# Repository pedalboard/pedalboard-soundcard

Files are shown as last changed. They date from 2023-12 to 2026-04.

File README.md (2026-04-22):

# Pedalboard Soundcard

I²S audio codec HAT for Raspberry Pi — ADC + DAC for the [Open Pedalboard](https://github.com/pedalboard) system.

**[Documentation →](https://pedalboard.github.io/pedalboard-soundcard/latest/)**

Top View

## Features

- TI Burr-Brown PCM1863 ADC (106dB SNR) + PCM5242 DAC (112dB SNR)
- Stereo differential input (guitar) + stereo output (amp)
- I²S interface to Raspberry Pi GPIO header
- Low-latency audio path for real-time effects
- Raspberry Pi HAT form factor

## Links

- [Interactive schematic & PCB viewer](https://pedalboard.github.io/pedalboard-soundcard/latest/board/)
- [Digi-Key shared list](https://www.digikey.ch/de/mylists/list/OT2O5ZLS9K)

## Development Setup

### Prerequisites

- [KiCad](https://www.kicad.org/) 10+
- [KiKit](https://github.com/yaqwsx/KiKit) (panelization)
- [mise](https://mise.jdx.dev/) (environment management)

### Environment

The schematic references KiKit's symbol and footprint libraries via the `${KIKIT_LIB}` environment variable. This is set per-machine using a `mise.local.toml` file (gitignored).

After cloning, create `mise.local.toml` in the project root:

```toml
[env]
KIKIT_LIB = "/path/to/kikit/resources"
```

Find your KiKit resources path with:

```sh
python3 -c "import kikit, os; print(os.path.join(os.path.dirname(kikit.__file__), 'resources'))"
```

Then trust the config:

```sh
mise trust mise.local.toml
```

### Checks

Run ERC and DRC:

```sh
make test
```

## Acknowledgements

Based on Dave Vandenbout's [RPi Hat Template](https://github.com/devbisme/RPi_Hat_Template).
Schematics derived from Jośe Fernando Moyano's [ZynADC](https://github.com/zynthian/zynthian-hw/tree/master/ZynADAC) ([CC BY-SA 4.0](https://creativecommons.org/licenses/by-sa/4.0/)).

## License



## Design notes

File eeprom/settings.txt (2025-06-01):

########################################################################
# EEPROM settings text file
#
# Edit this file for your particular board and run through eepmake tool,
# then use eepflash tool to write to attached HAT ID EEPROM 
#
# Tools available:
#  eepmake   Parses EEPROM text file and creates binary .eep file
#  eepdump   Dumps a binary .eep file as human readable text (for debug)
#  eepflash  Write or read .eep binary image to/from HAT EEPROM
#
########################################################################

########################################################################
# Vendor info

# 128 bit UUID. If left at zero eepmake tool will auto-generate
# RFC 4122 compliant UUID
product_uuid 8b12a93d-56c9-435f-b7e0-9d4ae88997cc

# 16 bit product id
product_id 0x0001

# 16 bit product version
product_ver 0x0001

# ASCII vendor string  (max 255 characters)
vendor "github.com/pedalboard"

# ASCII product string (max 255 characters)
product "pedalboard-soundcard"

########################################################################
# GPIO bank settings, set to nonzero to change from the default.
# NOTE these setting can only be set per BANK, uncommenting any of
# these will force the bank to use the custom setting.

# drive strength, 0=default, 1-8=2,4,6,8,10,12,14,16mA, 9-15=reserved
gpio_drive 0

# 0=default, 1=slew rate limiting, 2=no slew limiting, 3=reserved
gpio_slew 0

# 0=default, 1=hysteresis disabled, 2=hysteresis enabled, 3=reserved
gpio_hysteresis 0

# If board back-powers Pi via 5V GPIO header pins:
# 0 = board does not back-power
# 1 = board back-powers and can supply the Pi with a minimum of 1.3A
# 2 = board back-powers and can supply the Pi with a minimum of 2A
# 3 = reserved
# If back_power=2 then USB high current mode will be automatically 
# enabled on the Pi
back_power 0

########################################################################
# GPIO pins, uncomment for GPIOs used on board
# Options for FUNCTION: INPUT, OUTPUT, ALT0-ALT5
# Options for PULL: DEFAULT, UP, DOWN, NONE
# NB GPIO0 and GPIO1 are reserved for ID EEPROM so cannot be set

#         GPIO  FUNCTION  PULL
#         ----  --------  ----
#setgpio  2     INPUT     DEFAULT
#setgpio  3     INPUT     DEFAULT
#setgpio  4     INPUT     DEFAULT
#setgpio  5     INPUT     DEFAULT
#setgpio  6     INPUT     DEFAULT
#setgpio  7     INPUT     DEFAULT
#setgpio  8     INPUT     DEFAULT
#setgpio  9     INPUT     DEFAULT
#setgpio  10    INPUT     DEFAULT
#setgpio  11    INPUT     DEFAULT
#setgpio  12    INPUT     DEFAULT
#setgpio  13    INPUT     DEFAULT
#setgpio  14    INPUT     DEFAULT
#setgpio  15    INPUT     DEFAULT
#setgpio  16    INPUT     DEFAULT
#setgpio  17    INPUT     DEFAULT
setgpio  18    INPUT     DEFAULT
setgpio  19    INPUT     DEFAULT
setgpio  20    INPUT     DEFAULT
setgpio  21    OUTPUT     DEFAULT
#setgpio  22    INPUT     DEFAULT
#setgpio  23    INPUT     DEFAULT
#setgpio  24    INPUT     DEFAULT
#setgpio  25    INPUT     DEFAULT
#setgpio  26    INPUT     DEFAULT
#setgpio  27    INPUT     DEFAULT

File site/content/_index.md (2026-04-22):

---
title: Overview
weight: 10
---

PCB 3D Render

I²S audio codec HAT for Raspberry Pi, designed for real-time guitar effects
processing in the [Open Pedalboard](https://github.com/pedalboard) system.

## Audio Specs

| | ADC (PCM1863) | DAC (PCM5242) |
|---|---|---|
| Resolution | 24-bit | 32-bit |
| Sample rate | up to 192 kHz | up to 384 kHz |
| SNR | 106 dB | 112 dB |
| THD+N | -93 dB | -93 dB |

## Features

- Stereo differential ADC input (guitar) + stereo DAC output (amp)
- TI Burr-Brown PCM1863 (ADC) and PCM5242 (DAC)
- I²S interface to Raspberry Pi GPIO header
- Low-latency audio path for real-time effects
- Raspberry Pi HAT form factor
- Dedicated low-noise LDO regulators for analog supply

## Related

- [Main Board](https://pedalboard.github.io/pedalboard-hw/latest/) — carrier board and MIDI controller
- [Display Board](https://pedalboard.github.io/pedalboard-display/latest/) — LED rings and OLED displays

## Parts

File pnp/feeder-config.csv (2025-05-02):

# |  | soundcard
# idx | type | id | name | part | enabled | location | refhole | lasthole
0 | strip | FDR18082b7f90ff6d45 | LH8-05 | Oscillator_SMD_Abracon_ASDMB-4Pin_2.5x2.0mm-24.576M | True | 2|0|0|0|-90.0000 | 2|75.1249|209.1139|8.4000|0 | 2|75.1620|213.3620|0|0
1 | strip | FDR18082da35e6da8a0 | LH8-06 | Oscillator_SMD_Abracon_ASDMB-4Pin_2.5x2.0mm-22.5792M | True | 2|0|0|0|-90.0000 | 2|63.9973|209.1139|8.4000|0 | 2|63.9791|213.4223|0|0
2 | strip | FDR18082ef066e21f88 | LH8-07 | SOT-23-5-AT24CS01-STUM | True | 2|0|0|0|90.0000 | 2|52.9366|209.1139|8.2000|0 | 2|53.0002|212.2299|0|0
3 | strip | FDR18082fce2e1989f6 | LH8-08 | SOT-23-5-NCP163 | True | 2|0|0|0|90.0000 | 2|41.6733|209.1139|8.1000|0 | 2|41.6980|213.2862|0|0
4 | strip | FDR17951439e7cd6f58 | LV8-01 | R_0805_2012Metric-100R | True | 2|0|0|0|90.0000 | 2|170.7350|198.7796|8.8000|0 | 2|170.8145|195.5087|0|0
5 | strip | FDR179514137f0b0a13 | LV8-02 | R_0805_2012Metric-470R | True | 2|0|0|0|90.0000 | 2|160.0952|198.7796|9.2000|0 | 2|160.0146|195.1096|0|0
6 | strip | FDR179513df1c674872 | LV8-03 | R_0805_2012Metric-10k | True | 2|0|0|0|90.0000 | 2|149.0850|198.7796|9.5000|0 | 2|149.0850|195.0340|0|0
7 | strip | FDR179513bd4cfa865e | LV8-04 | R_0805_2012Metric-100K | True | 2|0|0|0|90.0000 | 2|137.9097|198.7796|9.6000|0 | 2|137.8978|195.9155|0|0
8 | strip | FDR1795130d1cbdbcd5 | LV8-08 | LED_0805_2012Metric-LED_R | True | 2|0|0|0|-90.0000 | 2|92.9169|198.7796|9.5000|0 | 2|92.8505|191.6939|0|0
9 | strip | FDR18082c3ad540eca3 | LV8-09 | R_0805_2012Metric-3K9 | True | 2|0|0|0|90.0000 | 2|81.6007|198.7796|9.2000|0 | 2|81.6010|195.3340|0|0
10 | strip | FDR1795165a4c5adb67 | RH12-1 | HVQFN-32-1EP_5x5mm_P0.5mm_EP3.1x3.1mm_ThermalVias-PCM5242RHBR | True | 2|0|0|0|-90.0000 | 2|314.5132|210.8000|9.0000|0 | 2|314.5130|222.0000|0|0
11 | strip | FDR1808305a407516ed | RV16-1 | TSSOP-30_4.4x7.8mm_P0.5mm-PCM1863DBT | True | 2|0|0|0|0 | 2|366.1972|86.9000|10.0000|0 | 2|377.8060|86.9000|0|0
12 | strip | FDR17950f970e7eae6f | RV8-1 | C_0805_2012Metric-10n_film | True | 2|0|0|0|90.0000 | 2|272.8328|198.3038|8.5000|0 | 2|272.8307|194.3172|0|0
13 | strip | FDR179510d6aa94207a | RV8-2 | C_0805_2012Metric-100n | True | 2|0|0|0|90.0000 | 2|284.2360|199.3110|8.5000|0 | 2|284.2660|195.3660|0|0
14 | strip | FDR1795114ae91f5aa0 | RV8-3 | C_0805_2012Metric-1u | True | 2|0|0|0|90.0000 | 2|295.2742|198.2397|8.3000|0 | 2|295.2372|194.2400|0|0
15 | strip | FDR17951187bdd2d904 | RV8-4 | C_0805_2012Metric-10u | True | 2|0|0|0|90.0000 | 2|306.1177|198.0000|8.1000|0 | 2|306.1627|162.2117|0|0
16 | strip | FDR17951206a90bb1d3 | RV8-7 | C_0805_2012Metric-2n2 | True | 2|0|0|0|90.0000 | 2|339.7375|198.0000|8.5000|0 | 2|339.8131|194.0000|0|0

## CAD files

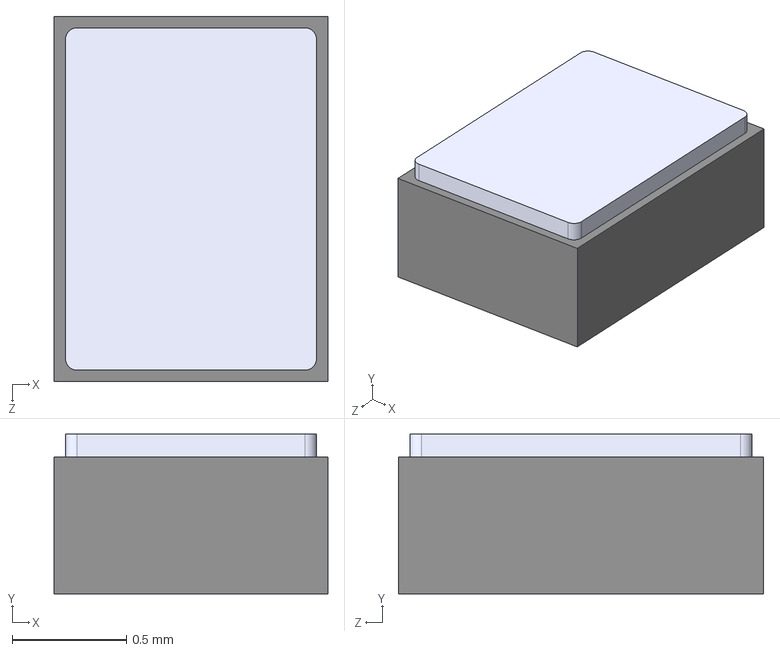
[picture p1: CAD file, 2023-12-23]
3d-models/ASCO.STEP
1.20 x 0.7 x 1.60 mm

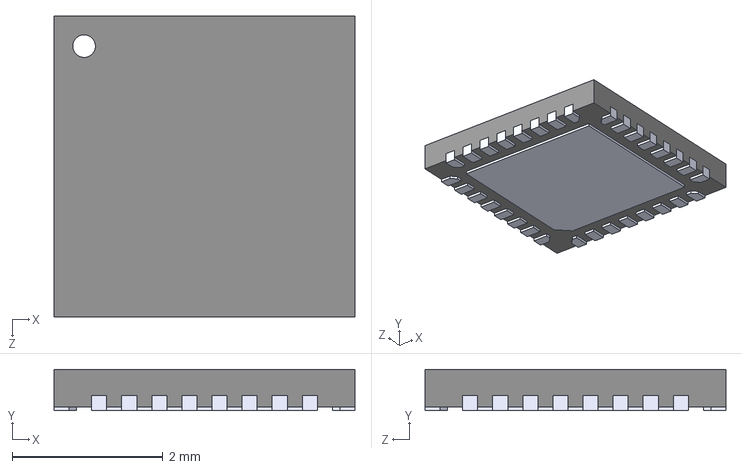
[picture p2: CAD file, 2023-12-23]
3d-models/EFM8BB31F32G-A-QFN32.STEP
4.00 x 0.55 x 4.00 mm

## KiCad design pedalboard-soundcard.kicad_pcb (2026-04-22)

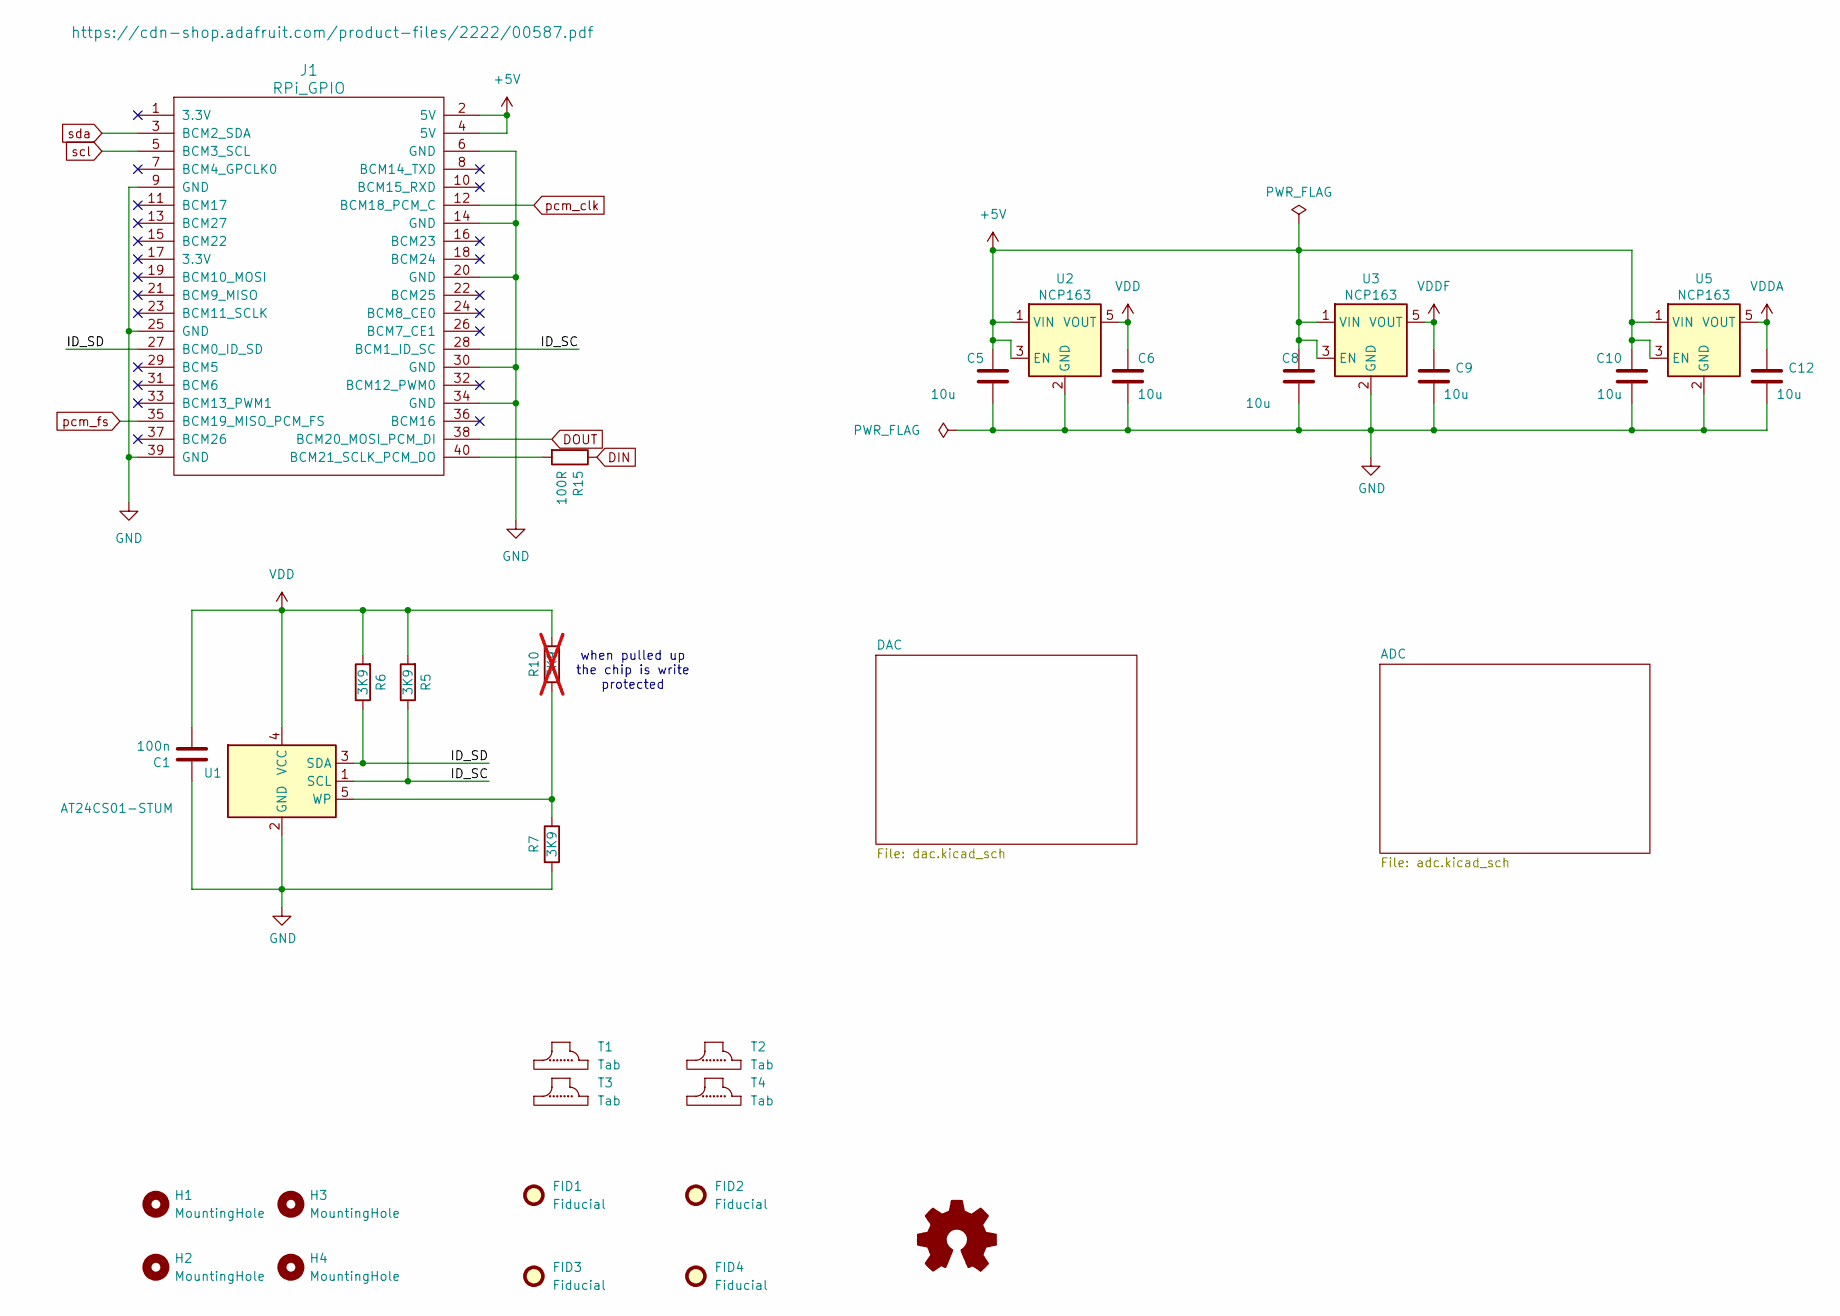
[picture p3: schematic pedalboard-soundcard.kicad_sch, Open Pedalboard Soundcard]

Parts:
C1: 100n; C_0805_2012Metric
C5, C6, C8, C9, C10, C12: 10u; C_0805_2012Metric
FID1, FID2, FID3, FID4: Fiducial; Fiducial_0.75mm_Mask1.5mm
H1, H2, H3, H4: MountingHole; RPi_Hat_Mounting_Hole
J1: RPi_GPIO; Pin_Header_Straight_2x20
R5, R6, R7: 3K9; R_0805_2012Metric
R10: 3K9; R_0805_2012Metric; not fitted
R15: 100R; R_0805_2012Metric
SYM1: Logo_Open_Hardware_Small; OSHW-Logo_5.7x6mm_SilkScreen
T1, T2, T3, T4: Tab
U1: AT24CS01-STUM; SOT-23-5
U2, U3, U5: NCP163; SOT-23-5

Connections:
+5V: C5.1, C8.1, C10.1, J1.2 (5V), J1.4 (5V), U2.1 (VIN), U2.3 (EN), U3.1 (VIN), U3.3 (EN), U5.1 (VIN), U5.3 (EN)
/ID_SC: J1.28 (BCM1_ID_SC), R5.1, U1.1 (SCL)
/ID_SD: J1.27 (BCM0_ID_SD), R6.1, U1.3 (SDA)
DIN: R15.1; also elsewhere on the board
DOUT: J1.38 (BCM20_MOSI_PCM_DI); also elsewhere on the board
GND: C1.1, C5.2, C6.2, C8.2, C9.2, C10.2, C12.2, J1.6 (GND), J1.9 (GND), J1.14 (GND), J1.20 (GND), J1.25 (GND), J1.30 (GND), J1.34 (GND), J1.39 (GND), R7.2, U1.2 (GND), U2.2 (GND), U3.2 (GND), U5.2 (GND); also elsewhere on the board
unnamed: J1.40 (BCM21_SCLK_PCM_DO), R15.2
unnamed: R7.1, R10.2, U1.5 (WP)
VDD: C1.2, C6.1, R5.2, R6.2, R10.1, U1.4 (VCC), U2.5 (VOUT); also elsewhere on the board
VDDA: C12.1, U5.5 (VOUT); also elsewhere on the board
VDDF: C9.1, U3.5 (VOUT); also elsewhere on the board
pcm_clk: J1.12 (BCM18_PCM_C); also elsewhere on the board
pcm_fs: J1.35 (BCM19_MISO_PCM_FS); also elsewhere on the board
scl: J1.5 (BCM3_SCL); also elsewhere on the board
sda: J1.3 (BCM2_SDA); also elsewhere on the board

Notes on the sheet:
when pulled up the chip is write protected

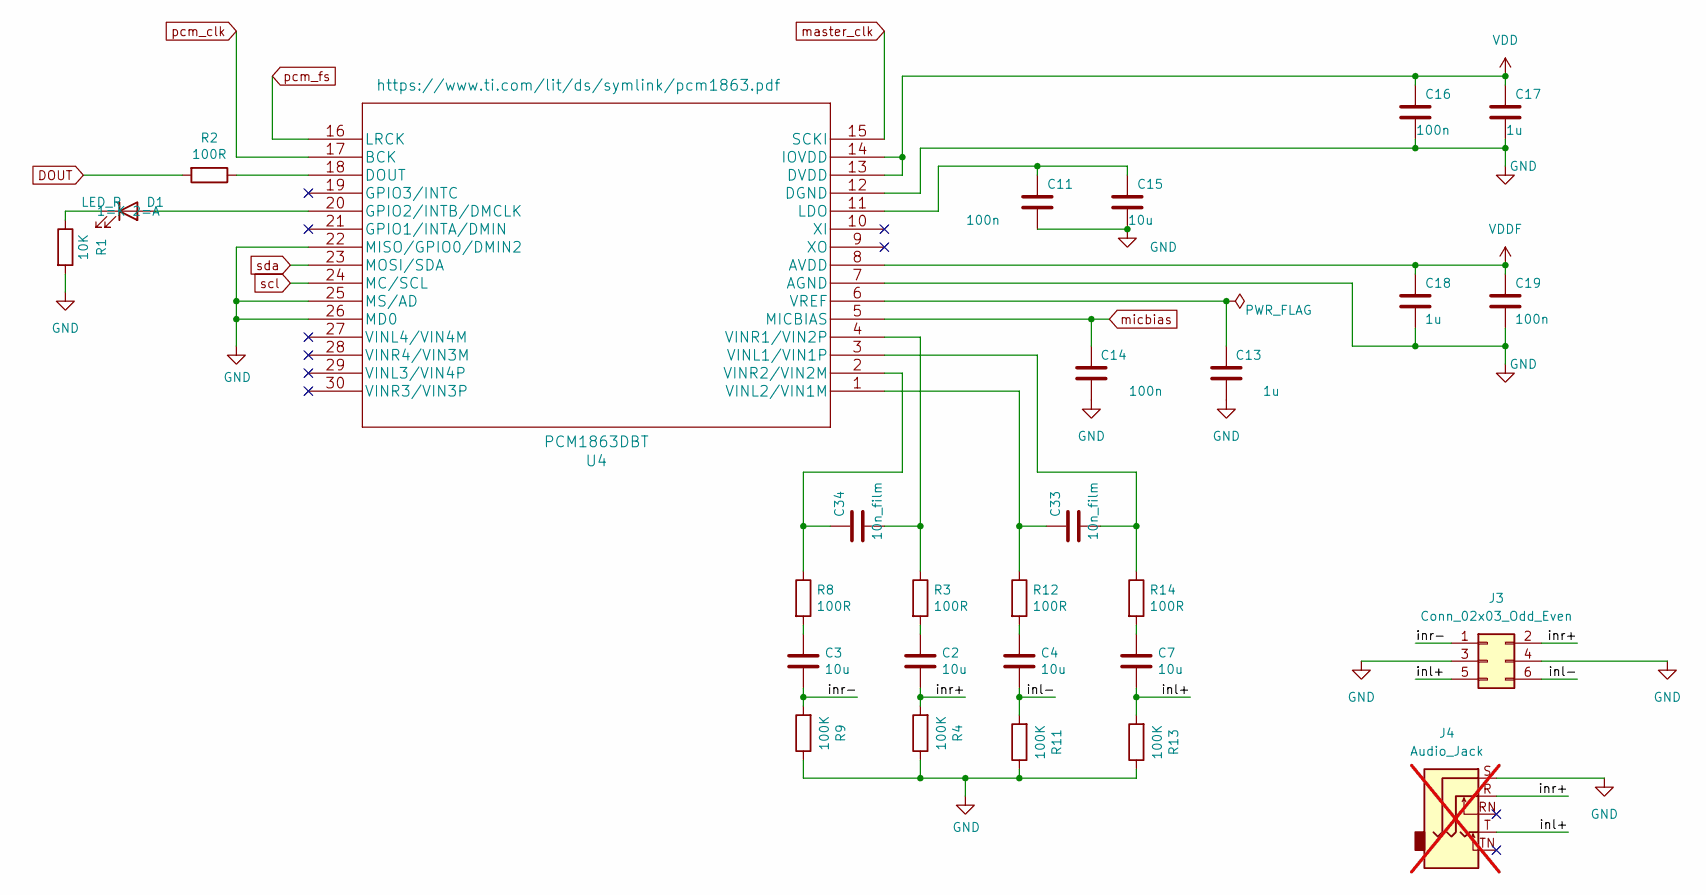
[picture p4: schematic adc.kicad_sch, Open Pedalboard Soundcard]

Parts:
C2, C3, C4, C7, C15: 10u; C_0805_2012Metric
C11, C14, C16, C19: 100n; C_0805_2012Metric
C13, C17, C18: 1u; C_0805_2012Metric
C33, C34: 10n_film; C_0805_2012Metric
D1: LED_R; LED_0805_2012Metric
J3: Conn_02x03_Odd_Even; PinSocket_2x03_P2.54mm_Vertical
J4: Audio_Jack; Jack_3.5mm_CUI_SJ1-3525N_Horizontal; not fitted
R1: 10K; R_0805_2012Metric
R2, R3, R8, R12, R14: 100R; R_0805_2012Metric
R4, R9, R11, R13: 100K; R_0805_2012Metric
U4: PCM1863DBT; TSSOP-30_4.4x7.8mm_P0.5mm

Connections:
/ADC/inl+: C7.2, J3.5, J4.T, R13.2
/ADC/inl-: C4.2, J3.6, R11.2
/ADC/inr+: C2.2, J3.2, J4.R, R4.2
/ADC/inr-: C3.2, J3.1, R9.2
DOUT: R2.2; also elsewhere on the board
GND: C11.2, C13.1, C14.1, C15.2, C16.2, C17.2, C18.2, C19.2, J3.3, J3.4, J4.S, R1.2, R4.1, R9.1, R11.1, R13.1, U4.7 (AGND), U4.12 (DGND), U4.22 (MISO/GPIO0/DMIN2), U4.25 (MS/AD), U4.26 (MD0); also elsewhere on the board
unnamed: C2.1, R3.2
unnamed: C3.1, R8.2
unnamed: C4.1, R12.2
unnamed: C7.1, R14.2
unnamed: D1.2 (A), U4.20 (GPIO2/INTB/DMCLK)
unnamed: D1.1 (K), R1.1
unnamed: R2.1, U4.18 (DOUT)
unnamed: C11.1, C15.1, U4.11 (LDO)
unnamed: C33.1, R14.1, U4.3 (VINL1/VIN1P)
unnamed: C33.2, R12.1, U4.1 (VINL2/VIN1M)
unnamed: C34.1, R3.1, U4.4 (VINR1/VIN2P)
unnamed: C34.2, R8.1, U4.2 (VINR2/VIN2M)
unnamed: C13.2, U4.6 (VREF)
VDD: C16.1, C17.1, U4.13 (DVDD), U4.14 (IOVDD); also elsewhere on the board
VDDF: C18.1, C19.1, U4.8 (AVDD); also elsewhere on the board
master_clk: U4.15 (SCKI); also elsewhere on the board
micbias: C14.2, U4.5 (MICBIAS)
pcm_clk: U4.17 (BCK); also elsewhere on the board
pcm_fs: U4.16 (LRCK); also elsewhere on the board
scl: U4.24 (MC/SCL); also elsewhere on the board
sda: U4.23 (MOSI/SDA); also elsewhere on the board

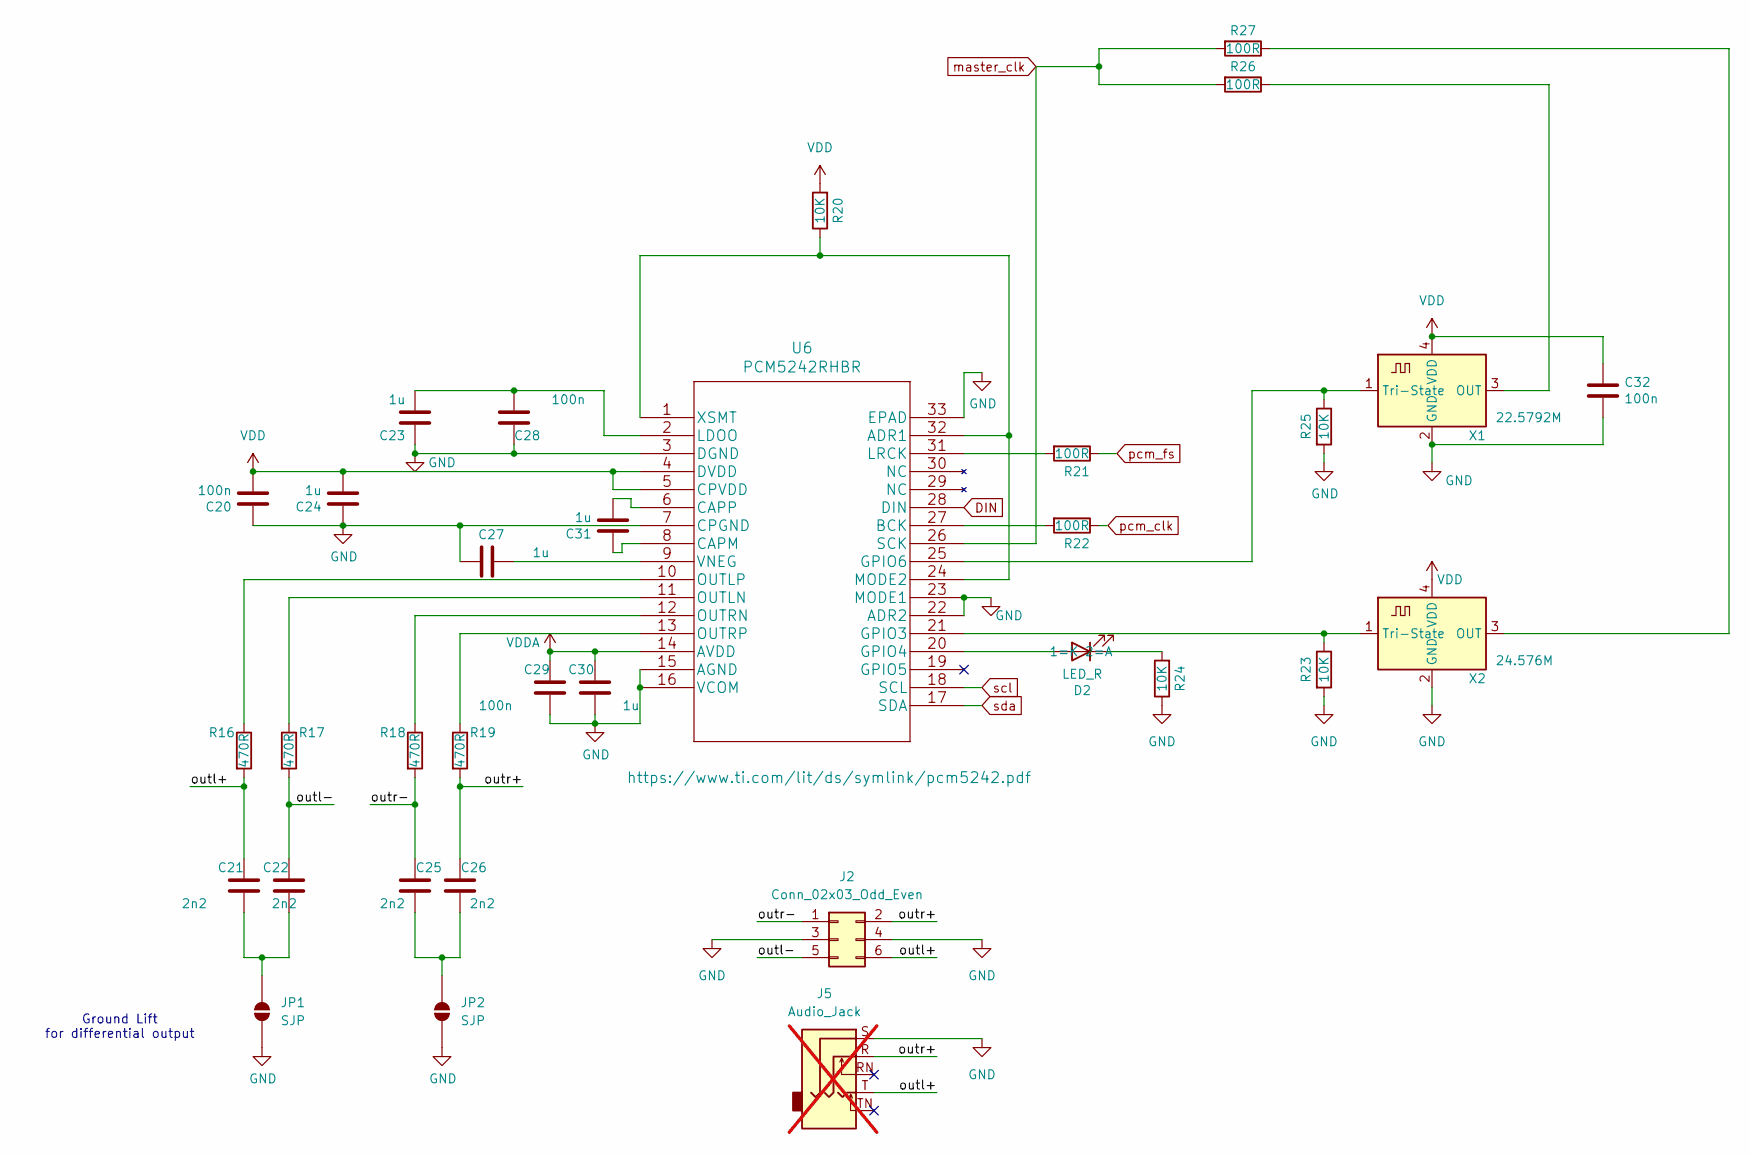
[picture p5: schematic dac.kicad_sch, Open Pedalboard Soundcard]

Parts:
C20, C28, C29, C32: 100n; C_0805_2012Metric
C21, C22, C25, C26: 2n2; C_0805_2012Metric
C23, C24, C27, C30, C31: 1u; C_0805_2012Metric
D2: LED_R; LED_0805_2012Metric
J2: Conn_02x03_Odd_Even; PinSocket_2x03_P2.54mm_Vertical
J5: Audio_Jack; Jack_3.5mm_CUI_SJ1-3525N_Horizontal; not fitted
JP1, JP2: SJP; SolderJumper-2_P1.3mm_Open_RoundedPad1.0x1.5mm
R16, R17, R18, R19: 470R; R_0805_2012Metric
R20, R23, R24, R25: 10K; R_0805_2012Metric
R21, R22, R26, R27: 100R; R_0805_2012Metric
U6: PCM5242RHBR; HVQFN-32-1EP_5x5mm_P0.5mm_EP3.1x3.1mm_ThermalVias
X1: 22.5792M; Oscillator_SMD_Abracon_ASDMB-4Pin_2.5x2.0mm
X2: 24.576M; Oscillator_SMD_Abracon_ASDMB-4Pin_2.5x2.0mm

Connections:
/DAC/outl+: C21.1, J2.6, J5.T, R16.2
/DAC/outl-: C22.1, J2.5, R17.2
/DAC/outr+: C26.1, J2.2, J5.R, R19.2
/DAC/outr-: C25.1, J2.1, R18.2
DIN: U6.28 (DIN); also elsewhere on the board
GND: C20.1, C23.1, C24.1, C27.1, C28.1, C29.2, C30.1, C32.2, J2.3, J2.4, J5.S, JP1.1 (A), JP2.1 (A), R23.2, R24.1, R25.2, U6.3 (DGND), U6.7 (CPGND), U6.15 (AGND), U6.16 (VCOM), U6.22 (ADR2), U6.23 (MODE1), U6.33 (EPAD), X1.2 (GND), X2.2 (GND); also elsewhere on the board
unnamed: D2.2 (A), U6.20 (GPIO4)
unnamed: D2.1 (K), R24.2
unnamed: C21.2, C22.2, JP1.2 (B)
unnamed: C25.2, C26.2, JP2.2 (B)
unnamed: R20.1, U6.1 (XSMT), U6.24 (MODE2), U6.32 (ADR1)
unnamed: R22.2, U6.27 (BCK)
unnamed: C31.1, U6.8 (CAPM)
unnamed: C31.2, U6.6 (CAPP)
unnamed: R23.1, U6.21 (GPIO3), X2.1 (Tri-State)
unnamed: R25.1, U6.25 (GPIO6), X1.1 (Tri-State)
unnamed: C23.2, C28.2, U6.2 (LDOO)
unnamed: R21.2, U6.31 (LRCK)
unnamed: R17.1, U6.11 (OUTLN)
unnamed: R16.1, U6.10 (OUTLP)
unnamed: R18.1, U6.12 (OUTRN)
unnamed: R19.1, U6.13 (OUTRP)
unnamed: C27.2, U6.9 (VNEG)
unnamed: R26.1, X1.3 (OUT)
unnamed: R27.1, X2.3 (OUT)
VDD: C20.2, C24.2, C32.1, R20.2, U6.4 (DVDD), U6.5 (CPVDD), X1.4 (VDD), X2.4 (VDD); also elsewhere on the board
VDDA: C29.1, C30.2, U6.14 (AVDD); also elsewhere on the board
master_clk: R26.2, R27.2, U6.26 (SCK); also elsewhere on the board
pcm_clk: R22.1; also elsewhere on the board
pcm_fs: R21.1; also elsewhere on the board
scl: U6.18 (SCL); also elsewhere on the board
sda: U6.17 (SDA); also elsewhere on the board

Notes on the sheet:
Ground Lift for differential output

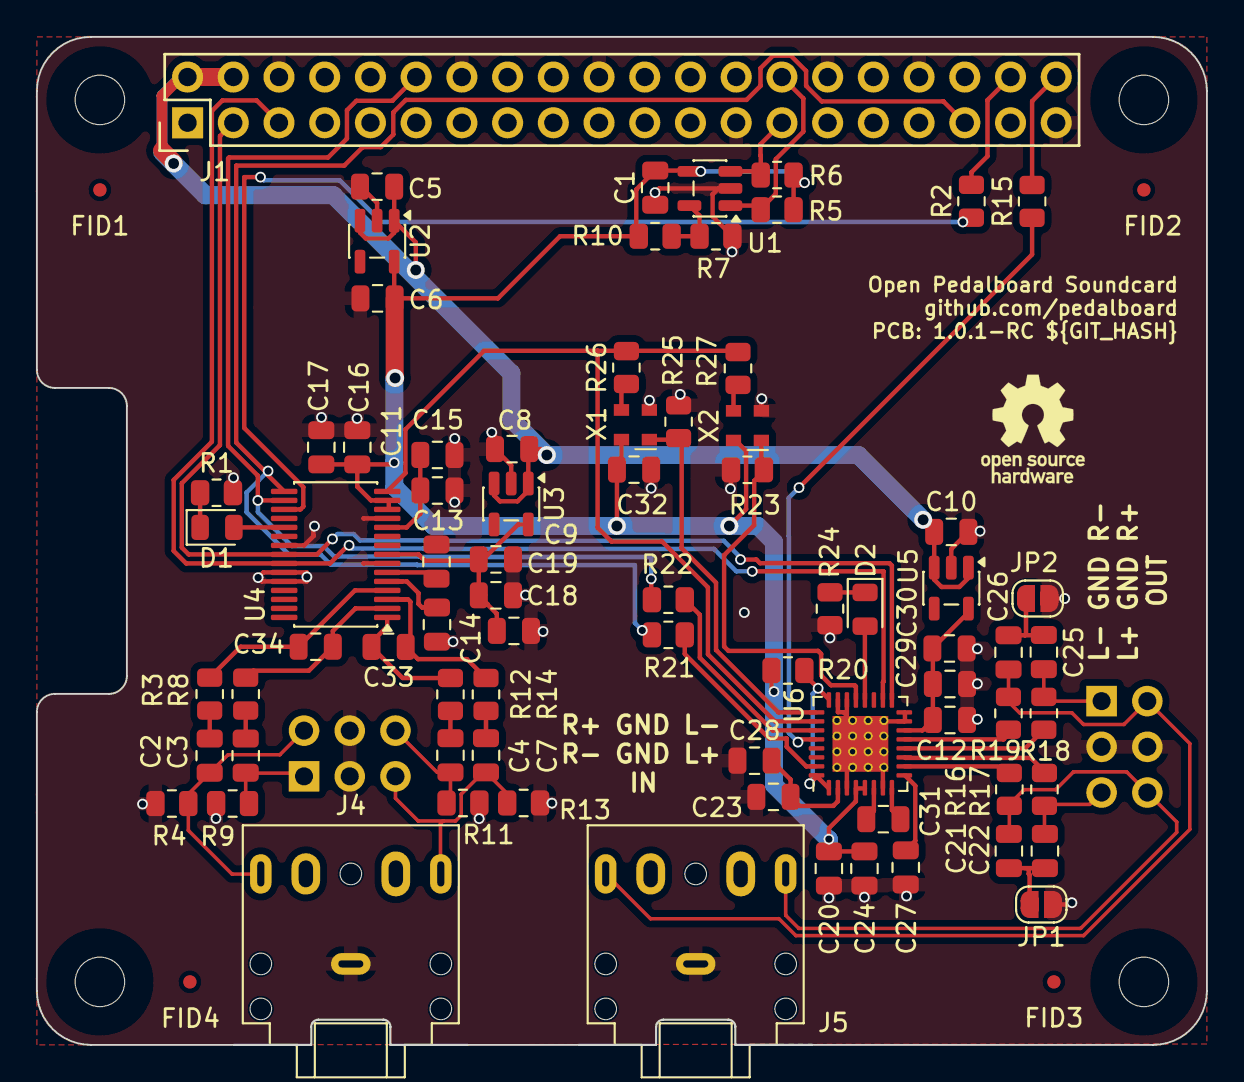
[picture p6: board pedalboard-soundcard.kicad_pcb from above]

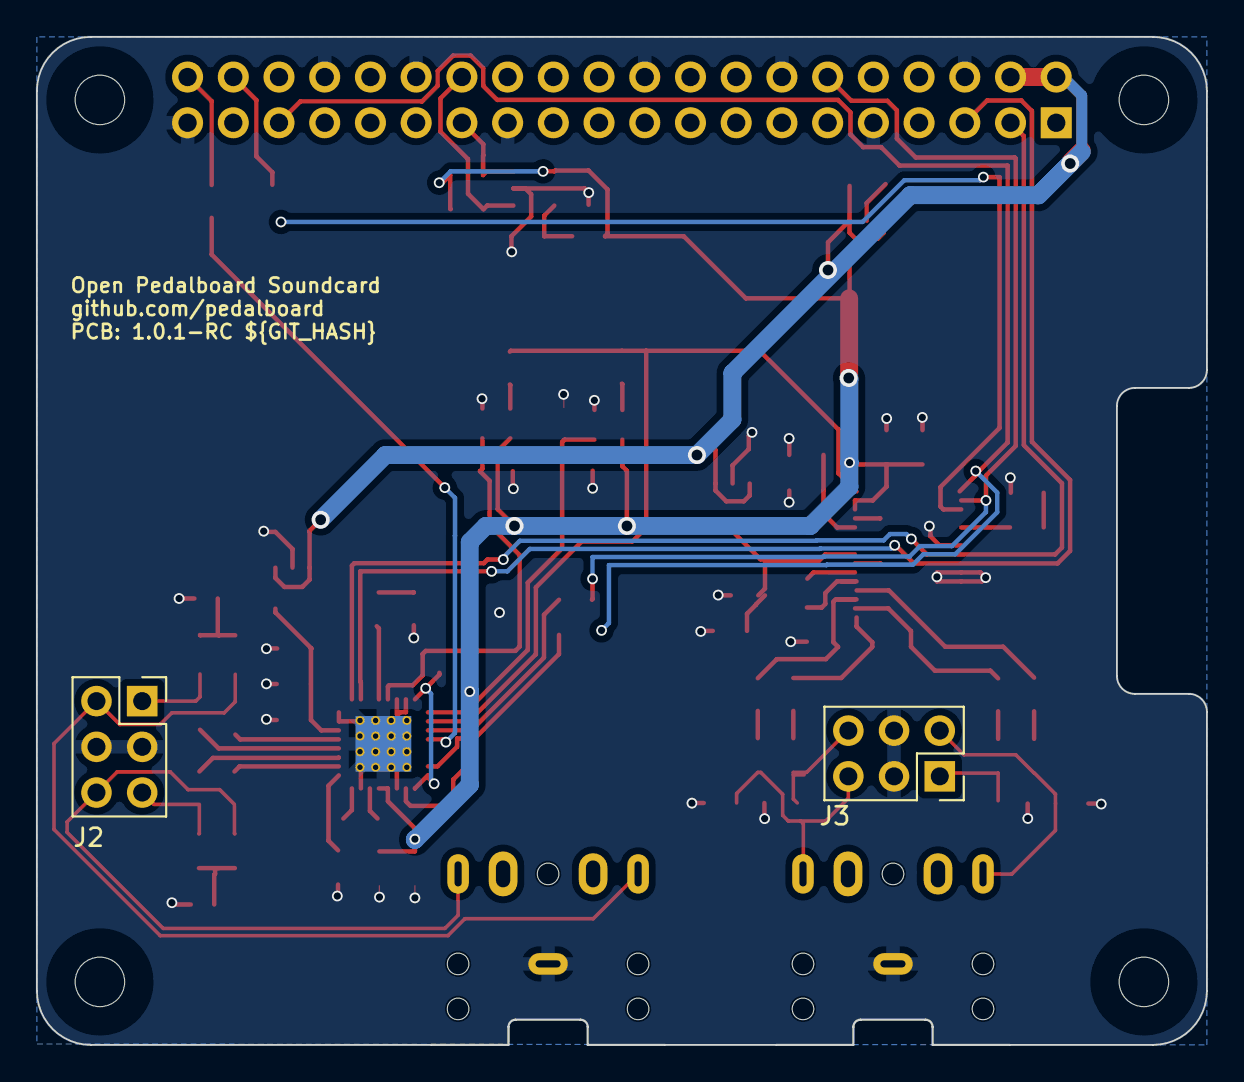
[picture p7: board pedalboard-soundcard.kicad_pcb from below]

Board: 2 copper layers, 65.0 x 56.0 mm, 91 parts (2 on the bottom side), 57 nets.

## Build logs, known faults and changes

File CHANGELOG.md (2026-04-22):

# Change Log

## TODO

- Mic bias support
- Improve XTAL footprint
- EEPROM size (32k)
- Too much solder paste on small pads

## 1.0.2 - KiCad 10 migration - 2026/04/22

- Migrate to KiCad 10 file format
- Update footprints from library
- Fix solder jumper symbol and footprint references
- Add KiKit library setup via mise environment variable
- Remove HPGL outputs (discontinued in KiCad 10)

## 1.0.1 - upgrades - 2025/10/16

- Upgrade to kicad 9.0

## [1.0.0 - First release - 2024/10/16

### Added

## Changed

### Fixed

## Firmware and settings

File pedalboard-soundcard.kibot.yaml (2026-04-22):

kibot:
  version: 1

global:
  kicad_dnp_applies_to_3D: true
  drc_exclusions_workaround: true
  filters:
    - number: 1007
    - number: 1015
    - number: 58

import:
  - file: Elecrow
  - file: FusionPCB
  - file: JLCPCB
  - file: MacroFab_XYRS
  - file: PCB2Blender_2_1
  - file: PCBWay

preflight:
  erc:
    enabled: true
  drc:
    enabled: true
  check_zone_fills: true
  ignore_unconnected: false
  set_text_variables:
    name: GIT_HASH
    command: git rev-parse --short HEAD

outputs:
  - name: basic_blender_export
    comment: 3D renders (Blender)
    type: blender_export
    dir: 3D
    options:
      pcb3d: _PCB2Blender_2_1
      add_default_light: false
      light:
        - name: sun
          type: SUN
          energy: 3
        - name: fill
          type: POINT
          pos_x: 'size*3'
          pos_y: '-size*3'
          pos_z: 'size*4'
          energy: 0
      render_options:
        resolution_x: 2560
        resolution_y: 1440
        samples: 20
        transparent_background: true
        auto_crop: true
      outputs:
        - type: render
      point_of_view:
        - rotate_x: 30
          rotate_z: -20
          file_id: _1_top
        - rotate_x: 210
          rotate_z: -20
          file_id: _2_bottom
  - name: basic_boardview
    comment: Board View export
    type: boardview
    dir: Assembly
  - name: generic_bom_html
    comment: Generic Bill of Materials in HTML format
    type: bom
    dir: BoM/Generic
    options:
      format: HTML
      count_smd_tht: true
  - name: generic_bom_csv
    comment: Generic Bill of Materials in CSV format
    type: bom
    dir: BoM/Generic
    options:
      format: CSV
      count_smd_tht: true
  - name: generic_bom_hrtxt
    comment: Generic Bill of Materials in HRTXT format
    type: bom
    dir: BoM/Generic
    options:
      format: HRTXT
      hrtxt:
        separator: "|"
      count_smd_tht: true
  - name: generic_bom_tsv
    comment: Generic Bill of Materials in TSV format
    type: bom
    dir: BoM/Generic
    options:
      format: TSV
      count_smd_tht: true
  - name: generic_bom_xml
    comment: Generic Bill of Materials in XML format
    type: bom
    dir: BoM/Generic
    options:
      format: XML
      count_smd_tht: true
  - name: generic_bom_xlsx
    comment: Generic Bill of Materials in XLSX format
    type: bom
    dir: BoM/Generic
    options:
      format: XLSX
      count_smd_tht: true
  - name: positional_bom_html
    comment: Positional Bill of Materials in HTML format
    type: bom
    dir: BoM/Positional
    options:
      format: HTML
      columns: &id001
        - Row
        - Description
        - Part
        - Part Lib
        - References
        - Value
        - Footprint
        - Footprint Lib
        - Quantity Per PCB
        - Build Quantity
        - Status
        - Datasheet
        - Supplier
        - Sheetpath
        - Source BoM
        - Footprint X
        - Footprint Y
        - Footprint Rot
        - Footprint Side
        - Footprint Type
        - Footprint Populate
        - Footprint X-Size
        - Footprint Y-Size
      count_smd_tht: true
      html:
        style: modern-red
  - name: positional_bom_xlsx
    comment: Positional Bill of Materials in XLSX format
    type: bom
    dir: BoM/Positional
    options:
      format: XLSX
      columns: *id001
      count_smd_tht: true
      xlsx:
        style: modern-red
  - name: costs_bom_xlsx
    comment: Costs Bill of Materials in XLSX format
    type: bom
    dir: BoM/Costs
    options:
      format: XLSX
      count_smd_tht: true
      xlsx:
        style: modern-green
        kicost: true
        specs: true
        kicost_api_disable: KitSpace
      pre_transform: _kicost_rename
  - name: macrofab_xyrs
    comment: Pick and place file, XYRS style
    extends: _macrofab_xyrs
    type: bom
    options:
      columns:
        - field: References
          name: Designator
        - field: Footprint X
          name: X-Loc
        - field: Footprint Y
          name: Y-Loc
        - field: Footprint Rot
          name: Rotation
        - field: Footprint Side
          name: Side
        - field: Footprint Type
          name: Type
        - field: Footprint X-Size
          name: X-Size
        - field: Footprint Y-Size
          name: Y-Size
        - field: Value
        - field: Footprint
        - field: Footprint Populate
          name: Populate
    dir: Position
  - name: basic_diff_pcb
    comment: PCB diff between the last two changes
    type: diff
    dir: diff
    layers:
      - layer: F.Cu
        suffix: F_Cu
        description: Front copper
      - layer: B.Cu
        suffix: B_Cu
        description: Bottom copper
      - layer: B.Silkscreen
        suffix: B_Silkscreen
        description: Bottom silkscreen (artwork)
      - layer: F.Silkscreen
        suffix: F_Silkscreen
        description: Front silkscreen (artwork)
      - layer: B.Mask
        suffix: B_Mask
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

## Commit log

2023-12-12 Initial revision
    [pedalboard-soundcard.kicad_pcb, pedalboard-soundcard.kicad_sch, pedalboard-soundcard.sch]
2023-12-19 First placement of parts on PCB
    [pedalboard-soundcard.kicad_pcb, pedalboard-soundcard.kicad_sch]
2023-12-19 Page settings
    [adc.kicad_sch, dac.kicad_sch, pedalboard-soundcard.kicad_pcb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]
2023-12-22 Distribute parts on PCB
    [adc.kicad_sch, dac.kicad_sch, pedalboard-soundcard.kicad_pcb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]
2023-12-23 First routing attempt
    [dac.kicad_sch, pedalboard-soundcard.kicad_pcb]
2023-12-23 Cleanup routing
    [adc.kicad_sch, dac.kicad_sch, pedalboard-soundcard.kicad_pcb]
2023-12-23 Releave the rules
    [pedalboard-soundcard.kicad_pcb]
2023-12-23 Fix 40pin connector silkscreen
    [pedalboard-soundcard.kicad_pcb]
2023-12-23 Improve 3d model
    [EFM8BB31F32G-A-QFN32.STEP, dac.kicad_sch, pedalboard-soundcard.kicad_pcb]
2023-12-23 Improve 3d models (XTAL)
    [dac.kicad_sch, pedalboard-soundcard.kicad_pcb]
2023-12-23 Cleanup placement
    [ASCO.STEP, pedalboard-soundcard.kicad_pcb, pedalboard-soundcard.kicad_sch]
2023-12-23 Minimum 0.3mm holes
    [pedalboard-soundcard.kicad_pcb]
2023-12-23 Dicrease material thickness
    [pedalboard-soundcard.kicad_pcb]
2023-12-23 Improve dimenstions
    [pedalboard-soundcard.kicad_pcb]
2023-12-23 Cleanup silkscreen
    [pedalboard-soundcard.kicad_pcb]
2023-12-23 PCB text
    [pedalboard-soundcard.kicad_pcb]
2023-12-26 improve BOM
    [adc.kicad_sch, dac.kicad_sch, pedalboard-soundcard.kicad_sch]
2023-12-26 Update from schematics
    [pedalboard-soundcard.kicad_pcb]
2023-12-27 Cleanup schematic for eeprom
    [pedalboard-soundcard.kicad_pcb, pedalboard-soundcard.kicad_sch]
2023-12-27 Replace 5v global label with +5V power
    [pedalboard-soundcard.kicad_pcb, pedalboard-soundcard.kicad_sch]
2023-12-27 Replace DVDD global label with VDD power symbol
    [adc.kicad_sch, dac.kicad_sch, pedalboard-soundcard.kicad_pcb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]
2023-12-27 Use VDD symbol instead of lines
    [dac.kicad_sch]
2023-12-27 Use more Power symbols
    [dac.kicad_sch]
2023-12-27 Simplify/cleanup schematic
    [dac.kicad_sch]
2023-12-27 Improve readability of schematics
    [adc.kicad_sch, dac.kicad_sch]
2023-12-27 Cleanup schematics again
    [adc.kicad_sch, dac.kicad_sch]
2023-12-27 Use Power Symbols for analog power
    [adc.kicad_sch, dac.kicad_sch, pedalboard-soundcard.kicad_pcb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]
2023-12-27 Add Fiducials and OSHW logo
    [pedalboard-soundcard.kicad_pcb, pedalboard-soundcard.kicad_sch]
2023-12-27 Smaller OSHW Logo
    [pedalboard-soundcard.kicad_pcb, pedalboard-soundcard.kicad_sch]
2023-12-27 Add texts for connectors
    [pedalboard-soundcard.kicad_pcb]
2023-12-27 Revert to standard RPI headers
    [adc.kicad_sch, dac.kicad_sch, pedalboard-soundcard.kicad_pcb]
2023-12-27 Fix reverted connectors
    [pedalboard-soundcard.kicad_pcb]
2023-12-27 Fix library
    [adc.kicad_sch, dac.kicad_sch, pedalboard-soundcard.kicad_sch]
2023-12-28 Add 3.5mm jack connectors
    [adc.kicad_sch, dac.kicad_sch, pedalboard-soundcard.kicad_pcb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]
2023-12-28 DNP 3.5mm jack connectors
    [adc.kicad_sch, dac.kicad_sch]
2023-12-28 Add digikey shared list
    [pedalboard-soundcard.kicad_sch]
2024-01-07 Try drc exclusion workaround
    [pedalboard-soundcard.kibot.yaml]
2024-01-07 Add git commit to schema sheets and PCB sheet
    [adc.kicad_sch, dac.kicad_sch, pedalboard-soundcard.kicad_pcb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]
2024-01-07 Silkscreen cleanup
    [pedalboard-soundcard.kicad_pcb]
2024-01-07 PCB ID also on B.Silkscreen
    [pedalboard-soundcard.kicad_pcb]
2024-03-12 Fix panlel syntax again
    [pedalboard-soundcard.kibot.yaml]
2024-03-12 (try to) Fix panlel syntax
    [pedalboard-soundcard.kibot.yaml]
2024-03-12 Add panel tabs
    [adc.kicad_sch, dac.kicad_sch, pedalboard-soundcard.kicad_pcb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]
2024-03-12 Add tooling and fiducials to frame
2024-03-12 Add post processing
    [pedalboard-soundcard.kicad_pcb]
2024-10-04 Upgrade to v8
    [adc.kicad_sch, dac.kicad_sch, pedalboard-soundcard.kicad_pcb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]
2024-10-04 3d zoom change
    [pedalboard-soundcard.kicad_pcb]
2024-10-14 DNP for pull up
    [pedalboard-soundcard.kicad_pcb, pedalboard-soundcard.kicad_sch]
2024-10-14 Ground Lift for differential output
    [dac.kicad_sch, pedalboard-soundcard.kicad_pcb]
2024-10-16 Fix errors and warnings
    [adc.kicad_sch, dac.kicad_sch, pedalboard-soundcard.kicad_pcb]
2024-10-16 Update footprints
    [adc.kicad_sch, dac.kicad_sch, pedalboard-soundcard.kicad_sch]
2024-10-16 Fix warnings. Add input capacitor
    [adc.kicad_sch, pedalboard-soundcard.kicad_pcb, pedalboard-soundcard.kicad_sch]
2024-10-16 Bump version to 1.0.0
    [adc.kicad_sch, dac.kicad_sch, pedalboard-soundcard.kicad_pcb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]
2024-10-16 Bump version to 1.0.1-RC
    [adc.kicad_sch, dac.kicad_sch, pedalboard-soundcard.kicad_pcb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]
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2024-12-15 Add first pnp job
    [adc.kicad_sch, dac.kicad_sch, pedalboard-soundcard.kicad_pcb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]
2024-12-15 Align LED value with other projects
    [adc.kicad_sch, dac.kicad_sch, pedalboard-soundcard.kicad_pcb]
2024-12-15 Update the oscilator part definitions
    [dac.kicad_sch, pedalboard-soundcard.kicad_pcb]
2024-12-15 Fix all DRC errors
    [pedalboard-soundcard.kicad_pcb]
2025-04-21 Schema: Update to kicad v9
    [adc.kicad_sch, dac.kicad_sch, pedalboard-soundcard.kicad_sch]
2025-04-21 PCB: Update to kicad v9
    [pedalboard-soundcard.kicad_pcb]
2025-04-21 Update from schema
    [pedalboard-soundcard.kicad_pcb]
2025-04-30 Fix pnp pcb hight
2025-05-02 Add pnp feeder config
    [feed_map.csv, feeder-config.csv]
2026-04-14 Deploy to gh-pages branch with version picker
    - Replace cross-repo deploy with gh-pages in same repo
    - Add version picker landing page
    - Tag-triggered versioned deploy
    - Update README URLs
2026-04-17 switch to hugo-kicad-site theme
    Replaces custom landing page and CI with the reusable Hugo theme.
    Board page (KiCanvas + gallery + iBOM), release page (downloads + diffs).
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2026-04-21 site: add .mise.toml, update theme vendor (hugo-kicad-site v1.0.3)
2026-04-21 ci: switch to KiCad 10 container with kicad-packages3d
2026-04-22 Migrate to KiCad 10 file format
    [adc.kicad_sch, dac.kicad_sch, pedalboard-soundcard.kicad_sch]
2026-04-22 Update footprints from library and adjust DRC severity settings
    [pedalboard-soundcard.kicad_pcb]
2026-04-22 Fix solder jumper footprint references and parity issues
    [dac.kicad_sch, pedalboard-soundcard.kicad_pcb]
2026-04-22 Gitignore local artifacts (KiCad history, Hugo build lock, site static)
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2026-04-22 Remove pcbdraw, render_3d and kikit_present outputs (keep Blender only)
2026-04-22 Install kicad-packages3d for Blender 3D export in CI
2026-04-22 Trigger rebuild (KICAD10_3DMODEL_DIR fix in reusable workflow)
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2026-05-06 Migrate site theme to Hextra (v1.1.0)
    [feeders.csv, pedalboard-soundcard.csv]
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2026-07-07 feat: add custom device tree overlay for pedalboard-soundcard
    Custom overlay replaces hifiberry-dacplusadcpro dependency:
    - PCM1863 ADC at 0x4a, PCM5242 DAC at 0x4d (same as HiFiBerry)
    - Uses the existing hifiberry kernel driver (compatible string)
    - EEPROM settings.txt already configured with pedalboard vendor/product
    - Makefile targets: overlay, eeprom, flash-eeprom
    Usage:
    make overlay # compile .dts → .dtbo
    make eeprom # build flashable EEPROM image
    make flash-eeprom # write to HAT EEPROM (auto-detect on boot)
    Note: Still uses 'hifiberry,hifiberry-dacplusadcpro' compatible string
    because the kernel machine driver matches on it. A fully custom driver
    would be needed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

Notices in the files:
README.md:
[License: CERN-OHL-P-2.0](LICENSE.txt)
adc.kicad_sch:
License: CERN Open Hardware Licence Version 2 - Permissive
